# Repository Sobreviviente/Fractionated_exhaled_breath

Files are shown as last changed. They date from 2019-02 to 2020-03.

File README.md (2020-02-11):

# Fractionated_exhaled_breath
Locación de archivos para equipo médico desarrollado por PhD. Marcelo Tuesta, Fundación Doctor Jorge Kaplan Meyer.

Códigos elaborados por Carlos Pizarro, Centro de Innovación y Robótica.

Links de interés:

[Printed spirometer](http://iotmusings.com/low-cost-spirometer/)

[Printed spirometer 2](https://www.instructables.com/id/Low-Cost-Spirometer/)

[Printed spirometer 3](http://fabacademy.org/2019/labs/bahrain/students/zahra-almukhariq/projects/final-project/)

[Design and implementation of a spirometer](https://editorial.udistrital.edu.co/contenido/c-778.pdf)

[Lilly spirometer](http://langster1980.blogspot.com/2017/04/create-spirometer-using-msp7002dp.html)

[General spirometry info](http://docs.neu.edu.tr/library/6682401378.pdf)

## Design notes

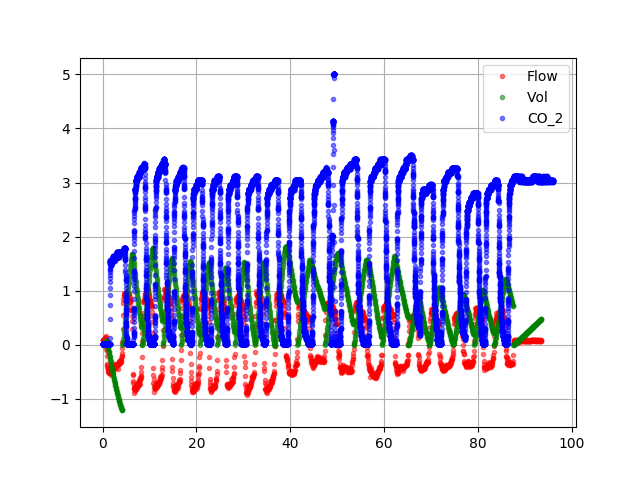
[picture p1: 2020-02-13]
Toma de datos co2 trigger 11-02-20/filtrados/c50-flow.png

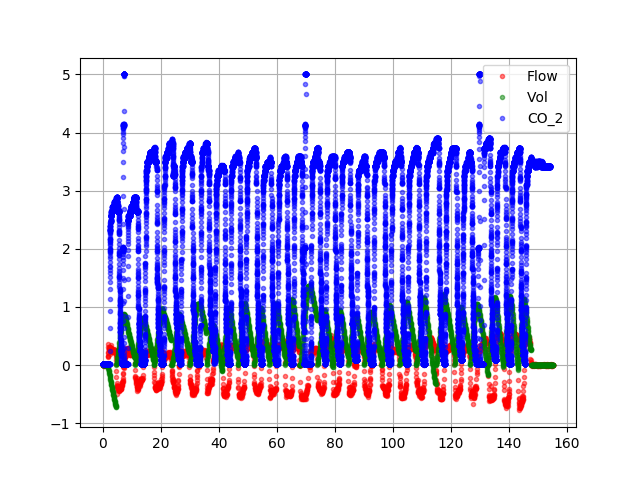
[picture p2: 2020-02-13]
Toma de datos co2 trigger 11-02-20/filtrados/c50-flow-2.png

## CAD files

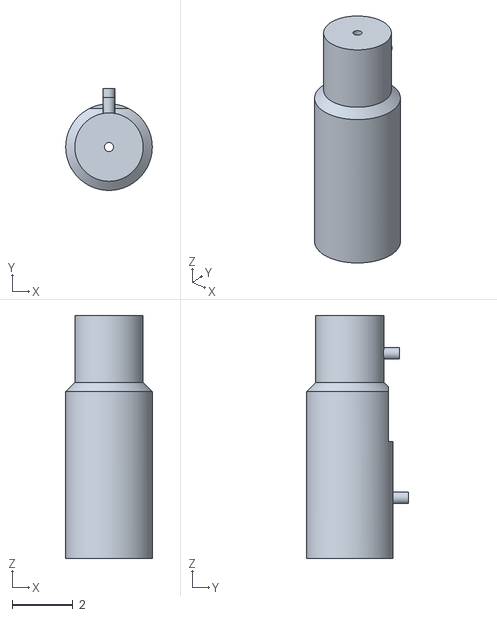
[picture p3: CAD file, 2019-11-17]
Int 3 2.stl
2.85 x 3.35 x 8.00

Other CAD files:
int 3.2.ipt

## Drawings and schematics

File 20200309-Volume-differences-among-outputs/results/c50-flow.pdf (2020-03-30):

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

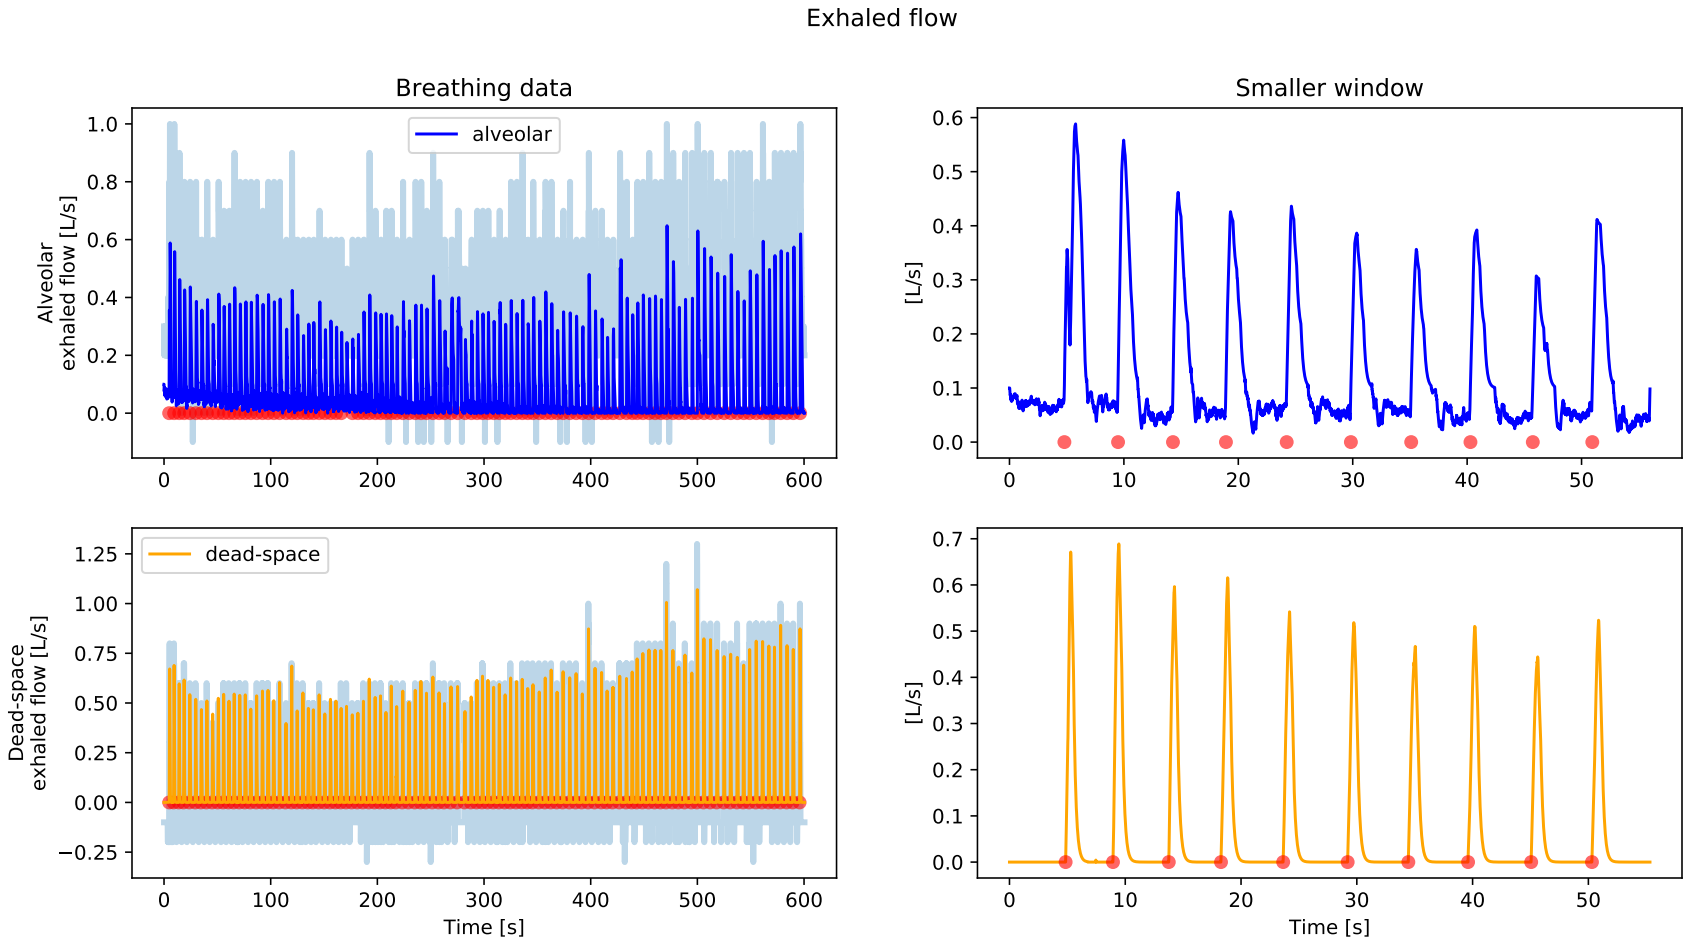
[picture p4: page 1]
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

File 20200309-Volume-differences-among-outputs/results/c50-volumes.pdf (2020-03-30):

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

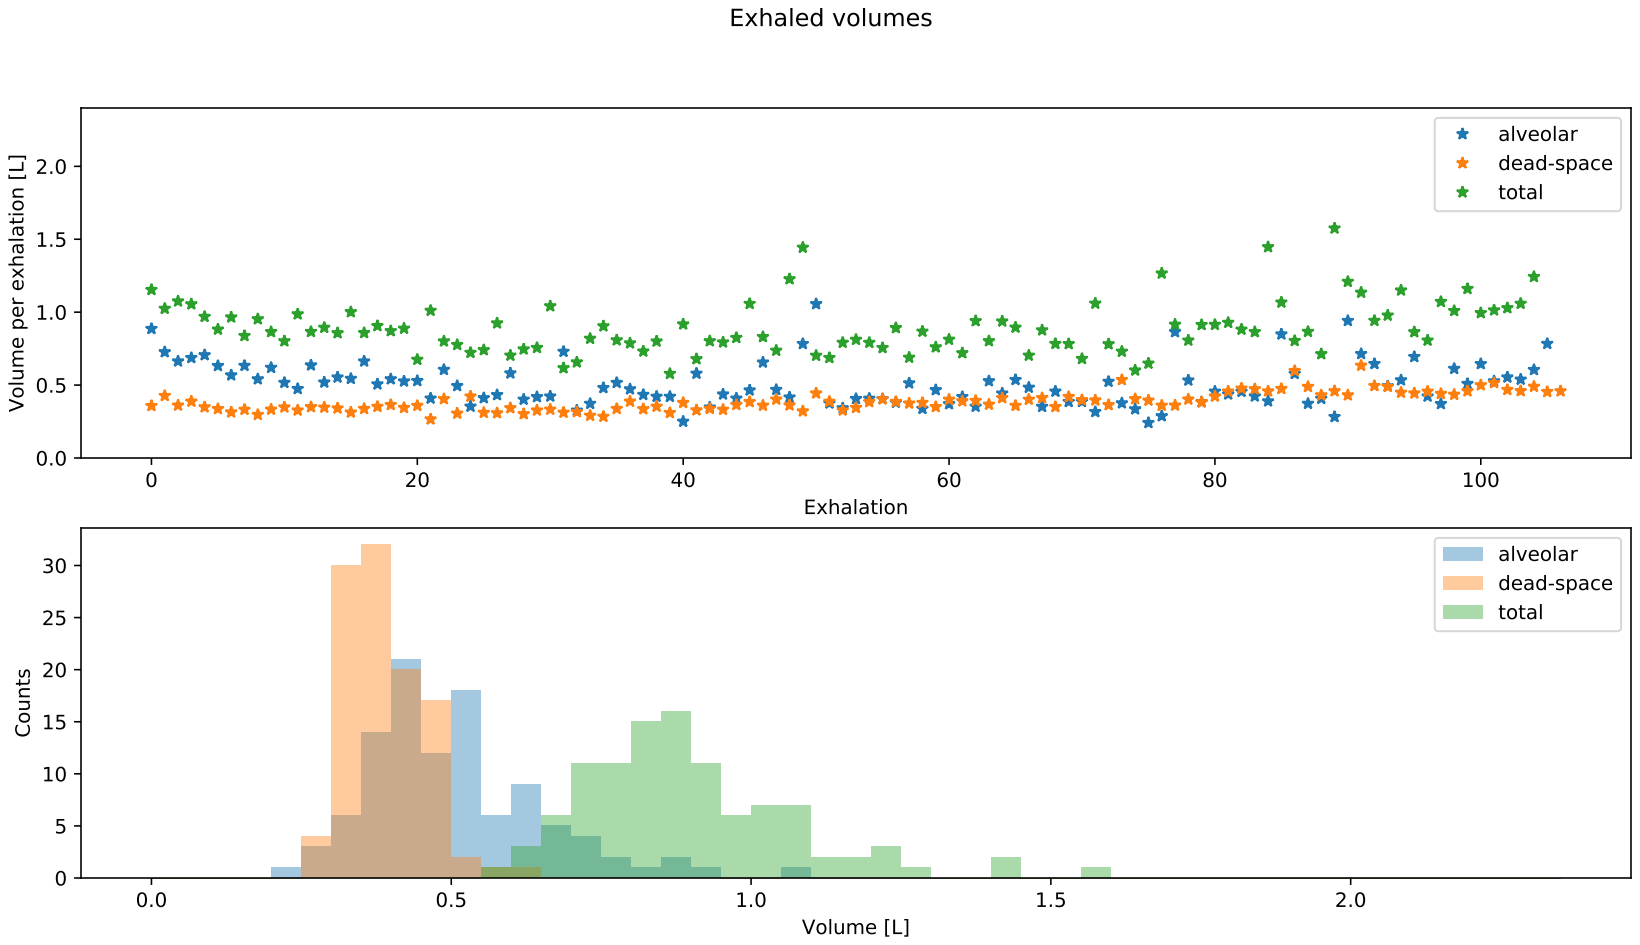
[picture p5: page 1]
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

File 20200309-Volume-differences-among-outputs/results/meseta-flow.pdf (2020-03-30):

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

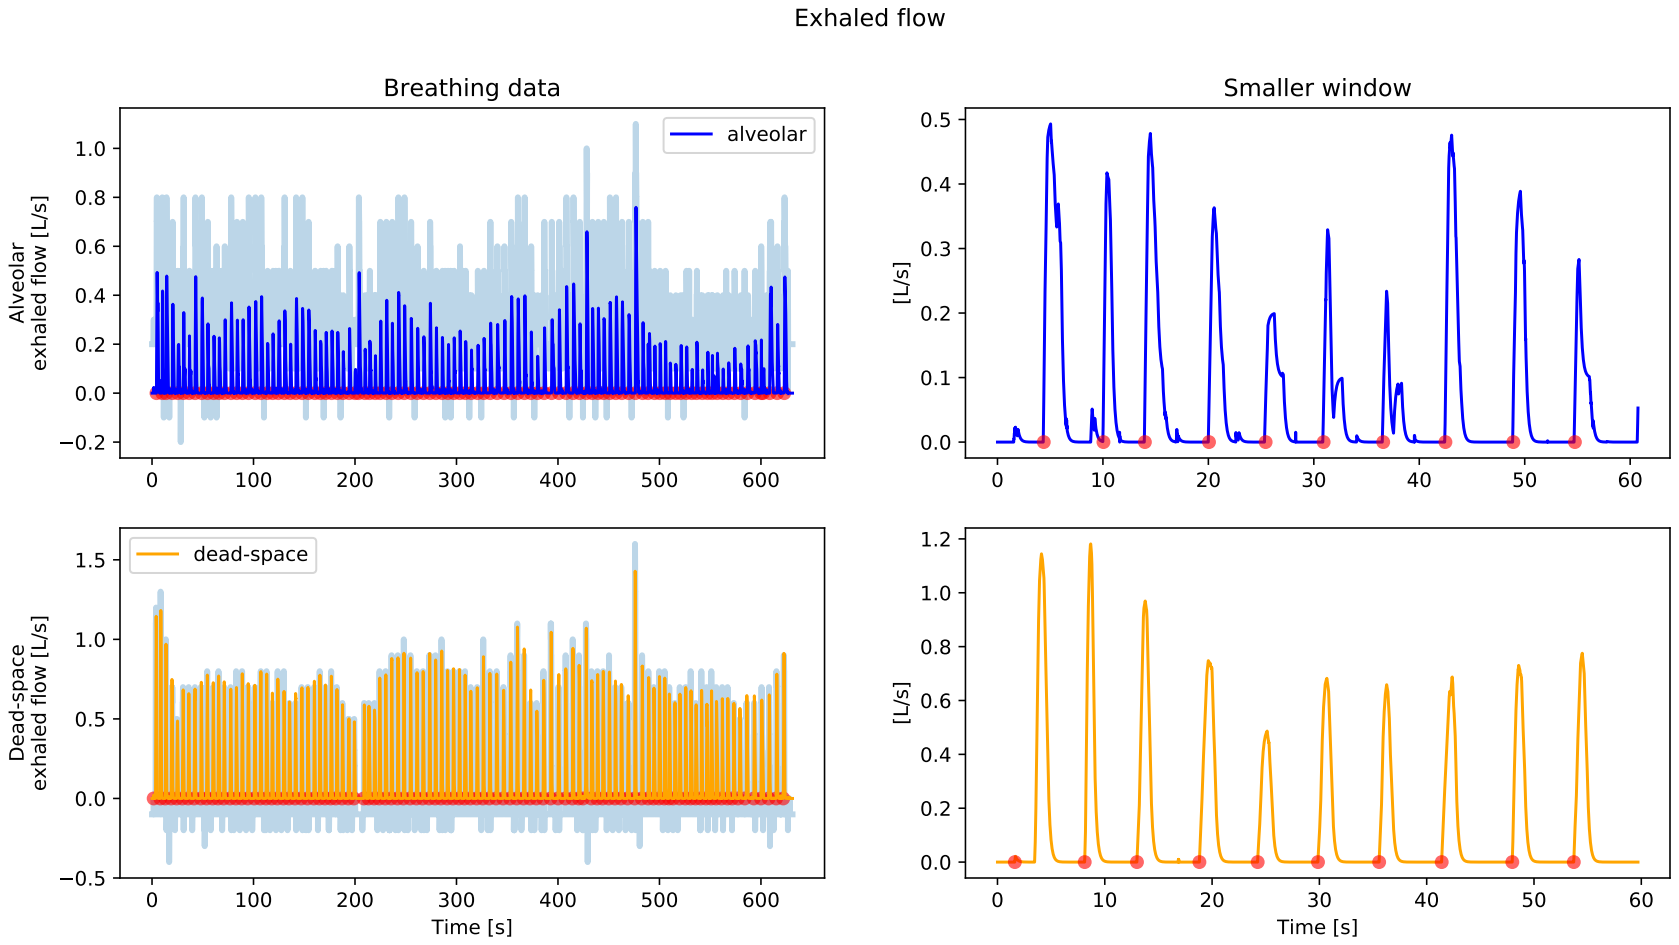
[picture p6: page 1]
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

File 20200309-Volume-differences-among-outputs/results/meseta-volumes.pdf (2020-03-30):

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

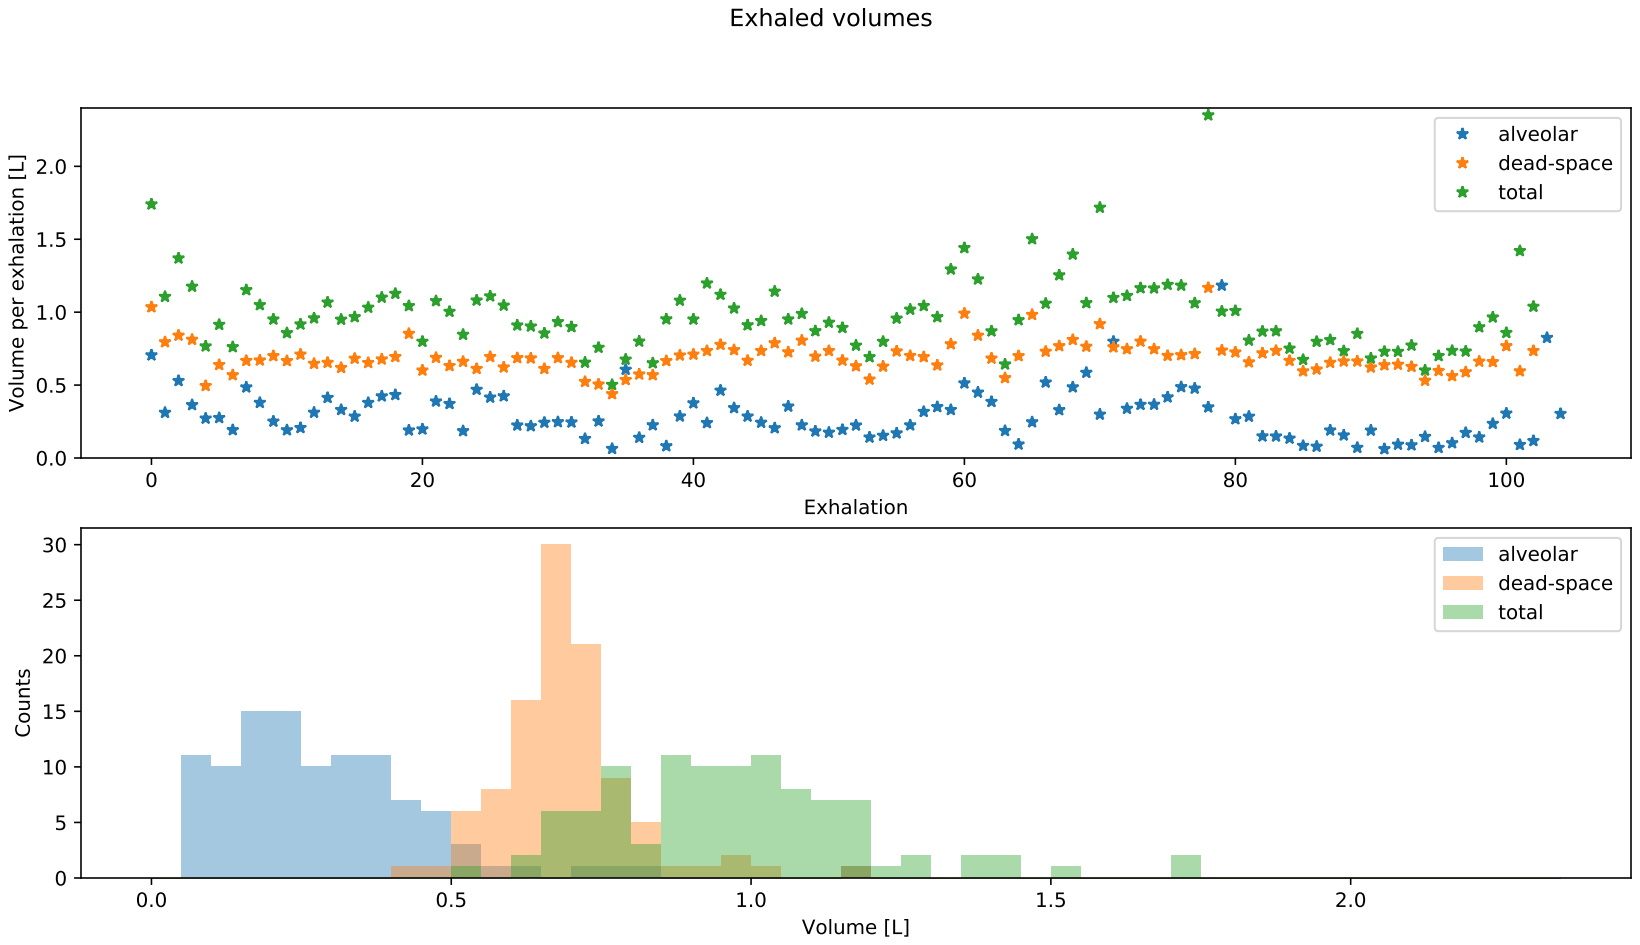
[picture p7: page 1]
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

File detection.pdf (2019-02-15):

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

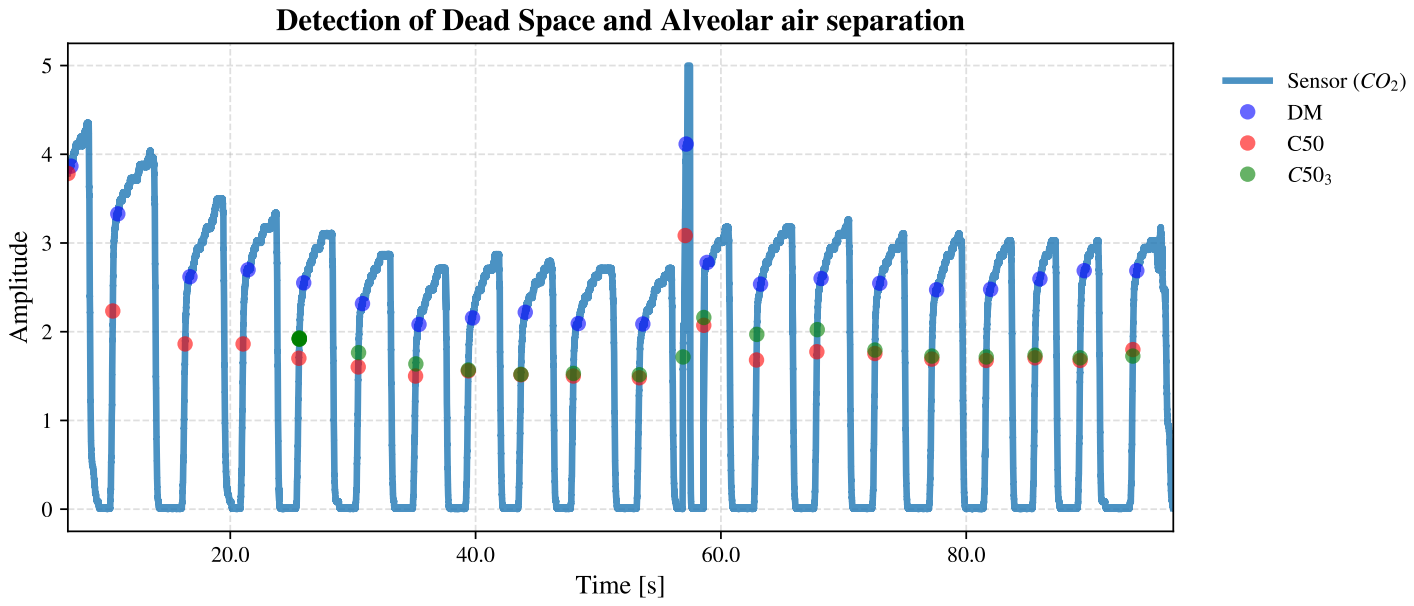
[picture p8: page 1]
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

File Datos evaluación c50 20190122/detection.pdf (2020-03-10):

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

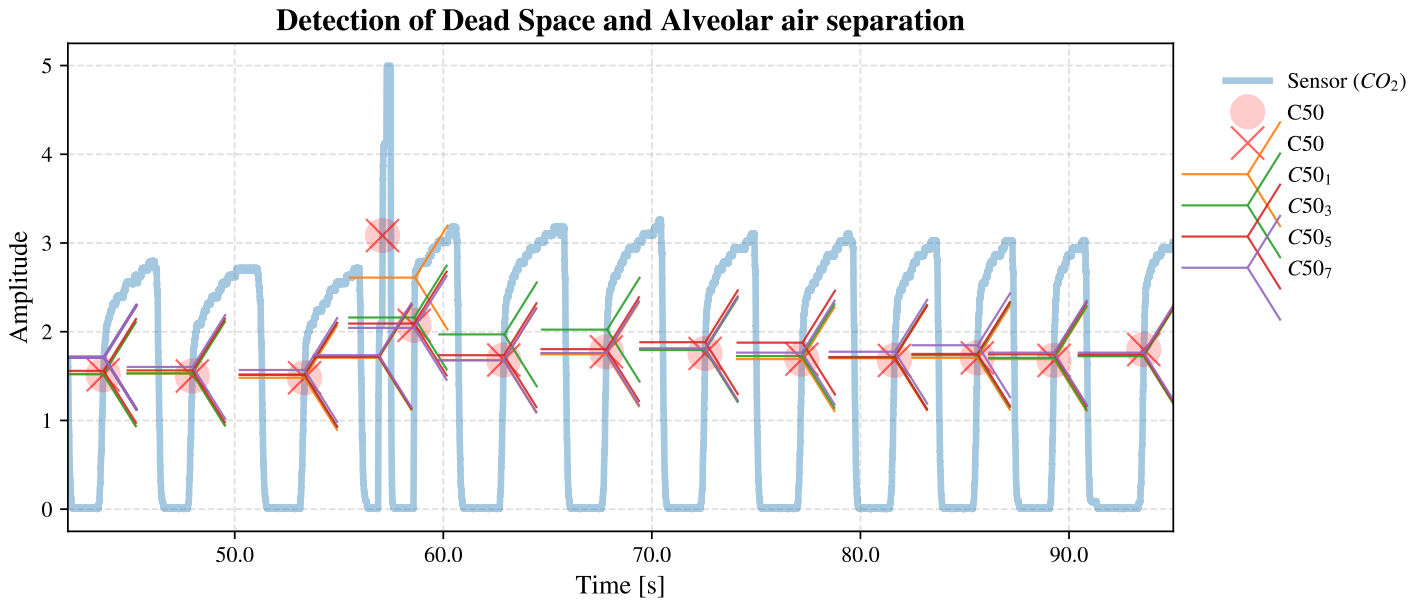
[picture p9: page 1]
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

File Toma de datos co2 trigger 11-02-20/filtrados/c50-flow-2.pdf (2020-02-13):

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

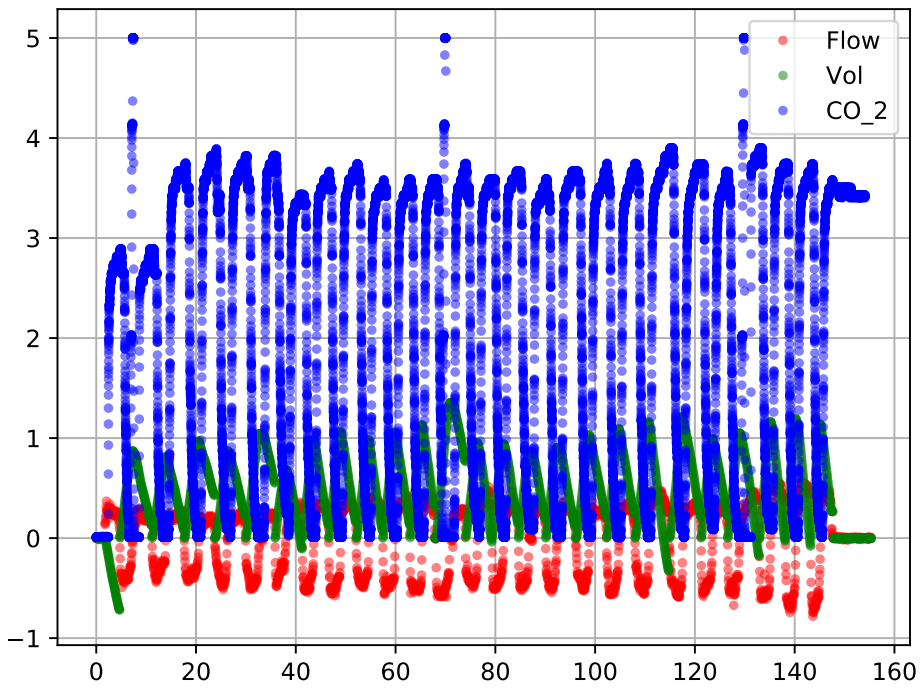
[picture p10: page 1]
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

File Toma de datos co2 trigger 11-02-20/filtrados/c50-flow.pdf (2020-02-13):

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

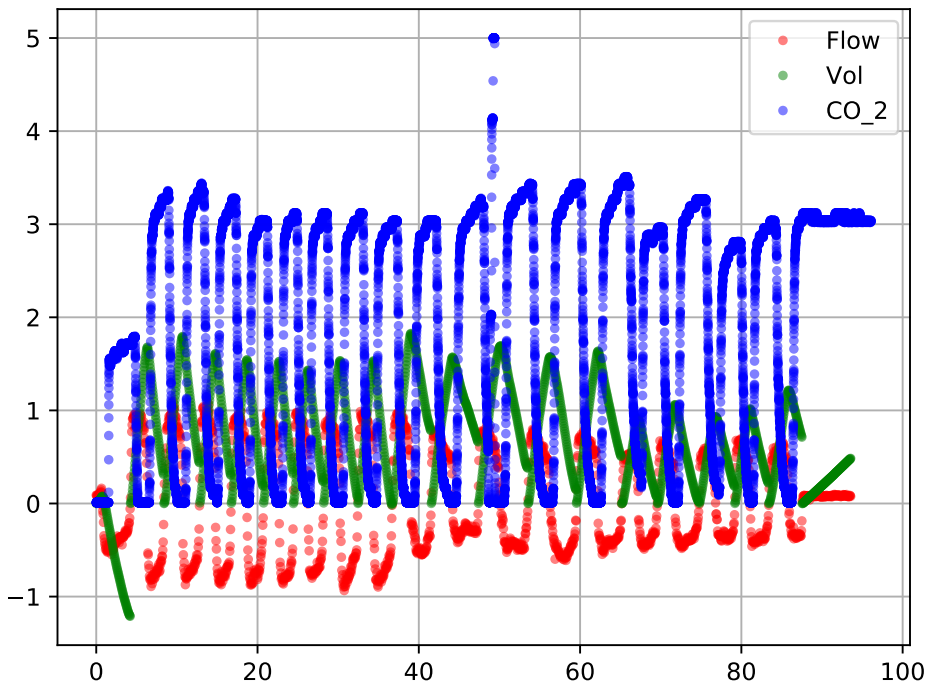
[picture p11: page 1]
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

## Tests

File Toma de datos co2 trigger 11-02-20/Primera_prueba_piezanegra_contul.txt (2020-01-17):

0.02098,2409288620,2409299,0.02986
0.02785,2409501544,2409512,0.09160
0.02785,2409781140,2409792,0.12042
0.03052,2411717296,2411727,0.87114
0.03052,2411763464,2411774,0.02116
0.07057,2411831860,2411842,0.04655
0.02976,2411855776,2411867,0.05767
0.06828,2411879712,2411890,0.07316
0.12665,2411903644,2411914,0.09517
0.06218,2411928724,2411939,0.11123
0.09613,2411966164,2411976,0.14080
0.03586,2412003604,2412014,0.15934
0.04730,2412041040,2412052,0.18064
0.02632,2412078484,2412089,0.19611
0.03319,2412115924,2412127,0.21395
0.04005,2412153364,2412164,0.23303
0.06294,2412190804,2412201,0.25696
0.05150,2412228244,2412238,0.27860
0.04730,2412265684,2412276,0.29989
0.07248,2412303136,2412314,0.32626
0.02022,2412362792,2412374,0.02199
0.02174,2412798112,2412809,0.16531
0.06371,2412822032,2412832,0.18027
0.21820,2412845984,2412857,0.21036
0.33188,2412869920,2412880,0.24451
0.42992,2412894960,2412906,0.28844
0.49210,2412932400,2412943,0.35533
0.54093,2412969844,2412981,0.42736
0.67216,2413007280,2413018,0.50553
0.75685,2413044724,2413056,0.59073
0.75189,2413082160,2413092,0.67118
0.74464,2413119600,2413130,0.75568
0.70459,2413157040,2413167,0.83572
0.73777,2413194480,2413205,0.91983
0.70039,2413231924,2413243,1.00179
0.73167,2413269360,2413280,1.08335
0.72976,2413306804,2413318,1.16701
0.81369,2413344240,2413355,1.25302
0.88617,2413381680,2413392,1.34278
0.95369,2413419120,2413429,1.43590
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

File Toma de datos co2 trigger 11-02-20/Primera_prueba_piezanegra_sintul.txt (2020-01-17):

2.61959,1028540448,1028551,5.20201
2.55245,1028577888,1028588,5.35435
2.47921,1028615328,1028626,5.50855
2.41131,1028652768,1028663,5.65661
2.51125,1028690208,1028701,5.81180
2.53033,1028727648,1028739,5.96758
2.41970,1028765088,1028775,6.11189
2.36591,1028802528,1028813,6.26252
2.38766,1028839968,1028850,6.40986
2.11604,1028877408,1028888,6.55232
2.01076,1028914848,1028925,6.68753
2.00809,1028952288,1028963,6.82630
1.86618,1028989736,1029001,6.96008
1.90356,1029027168,1029038,7.09164
1.74182,1029064608,1029075,7.21748
1.74716,1029102048,1029112,7.34352
1.63424,1029139488,1029150,7.46871
1.67277,1029176928,1029187,7.59203
1.82155,1029214368,1029225,7.72420
1.74258,1029251808,1029262,7.85007
1.66857,1029289248,1029300,7.97657
1.61784,1029326688,1029338,8.10113
1.57435,1029364128,1029374,8.21754
1.74983,1029401568,1029412,8.34708
1.61784,1029439008,1029449,8.46837
1.42634,1029476448,1029487,8.58532
1.25734,1029513888,1029524,8.69224
0.15984,1029551328,1029562,8.73140
0.02899,1029588776,1029600,8.74807
0.06447,1030248860,1030259,0.43121
0.04616,1030361708,1030372,0.06257
0.04616,1030519036,1030530,0.08748
0.04540,1030731924,1030743,0.11695
0.10567,1030778092,1030789,0.03854
0.13428,1030824232,1030835,0.04344
0.09422,1030881500,1030892,0.04509
0.14229,1030938756,1030949,0.05541
0.06104,1030973780,1030984,0.02228
0.05493,1031031048,1031042,0.03503
0.04349,1031054956,1031065,0.04739
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

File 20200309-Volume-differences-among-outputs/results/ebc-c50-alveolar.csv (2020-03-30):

start | end | volume
4.8 | 9.49 | 0.8862095103958444
9.49 | 14.29 | 0.7267876578773813
14.29 | 18.92 | 0.6635060401361577
18.92 | 24.23 | 0.6870290316965323
24.23 | 29.84 | 0.7061063877140579
29.84 | 35.11 | 0.6321993801062449
35.11 | 40.29 | 0.5679082054055556
40.29 | 45.74 | 0.63313496750012
45.74 | 50.94 | 0.5409160976201454
50.94 | 55.99 | 0.6195451129899768
55.99 | 60.98 | 0.5167137035342428
60.98 | 65.88 | 0.4745362277016411
65.88 | 71.09 | 0.6362130316414606
71.09 | 76.25 | 0.5188016796735437
76.25 | 81.44 | 0.5531982257852155
81.44 | 86.9 | 0.5440838656612225
86.9 | 92.37 | 0.6631409477341497
92.37 | 97.59 | 0.5060835650327001
97.59 | 102.99 | 0.5410553001332746
102.99 | 108.44 | 0.5261380702780186
108.44 | 114.5 | 0.5291754436900556
114.5 | 119.82 | 0.4088225360289564
119.82 | 124.96 | 0.6057315837603539
124.96 | 130.48 | 0.49481846637111704
130.48 | 135.43 | 0.3535004509640978
135.43 | 140.12 | 0.4114025079881202
140.12 | 145.53 | 0.43261954494099186
145.53 | 150.89 | 0.5814048738815037
150.89 | 156.15 | 0.40123948954407207
156.15 | 161.3 | 0.4188608197768126
161.3 | 166.16 | 0.42292958775837797
166.16 | 176.65 | 0.7295689840433791
176.65 | 181.89 | 0.3260135787325553
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

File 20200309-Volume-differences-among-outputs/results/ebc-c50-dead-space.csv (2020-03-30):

start | end | volume
4.85 | 8.94 | 0.358064465513996
8.94 | 13.76 | 0.4269477696528208
13.76 | 18.27 | 0.3609971732573878
18.27 | 23.64 | 0.3879990721000637
23.64 | 29.21 | 0.3489995485155068
29.21 | 34.45 | 0.33699956829402083
34.45 | 39.61 | 0.31399948998938815
39.61 | 45.06 | 0.33199951088236856
45.06 | 50.31 | 0.2969991233965058
50.31 | 55.33 | 0.3329991774964104
55.33 | 60.3 | 0.3479980144048592
60.3 | 65.22 | 0.32699896270985046
65.22 | 70.48 | 0.3501347913587115
70.48 | 75.67 | 0.3469950330662605
75.67 | 80.71 | 0.3409994811559704
80.71 | 86.34 | 0.31299940884935823
86.34 | 91.76 | 0.3379995928513026
91.76 | 96.97 | 0.35199947336349063
96.97 | 102.24 | 0.36499942904751925
102.24 | 107.87 | 0.34499934138563526
107.87 | 113.74 | 0.3589996111083369
113.74 | 119.25 | 0.2659993384007387
119.25 | 124.33 | 0.40499960860797224
124.33 | 129.62 | 0.30592100984609233
129.62 | 134.75 | 0.4228743895871633
134.75 | 139.44 | 0.31099930537437376
139.44 | 144.94 | 0.30799894458447546
144.94 | 150.16 | 0.3429996119278075
150.16 | 155.47 | 0.30199943346905106
155.47 | 160.64 | 0.3269995471874796
160.64 | 165.5 | 0.3329994028844408
165.5 | 170.57 | 0.3119993775837127
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

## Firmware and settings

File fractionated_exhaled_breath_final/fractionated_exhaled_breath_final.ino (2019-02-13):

#define PCe  0
#define Ce50 1
#define SUMA_TIEMPO 150000 // [ms]
float sensor_p=0;  // valor de sensor presion
float sensor_co2_1=0;  //valor de sensor co2 primer cable 
float sensor_co2_2=0;  //valor de sensor co2 segundo cable
char Key = '0';
int mensaje=0;
int estado_curva=0;
const int ledPin = 13; 
const int Bomba1 = 11;
const int Bomba2 = 12;
const int co2_1 = 23;
const int co2_2 = 22;
const int valv_blanca_1 = 16; //1 es el de la derecha
const int valv_negra_2 = 17;  // 2 es el de la izquierda 
const int valv_blanca_2 = 18;
const int valv_negra_1 = 19; 
unsigned long tiempo = 0;
unsigned long tiempo_t = 0;
uint8_t useMethod = PCe;
#define umbral_high 3.1
#define umbral_low 3.0
int estado_aux=0; 
float ultimos_3valores[3]={};
int c=0;
int pos=0;
float C50_maximo=-8;
float C50_minimo=8;
float C50_prom3=0;
bool C50_revisando = true;
unsigned long tiempo_trigger = 0; 

void setup() {
 Serial.begin(9600);
 pinMode( 20, INPUT); // pin 20 como input 
 pinMode( ledPin, OUTPUT);
 pinMode( Bomba1, OUTPUT);
 pinMode( Bomba2, OUTPUT);
 pinMode( co2_1, INPUT);
 pinMode( co2_2, INPUT);
 pinMode( valv_blanca_1, OUTPUT);
 pinMode( valv_negra_2, OUTPUT);
 pinMode( valv_blanca_2, OUTPUT);
 pinMode( valv_negra_1, OUTPUT);
  // put your setup code here, to run once:
  
  for (int i=0; i<3; i++){
      ultimos_3valores[i] = -1;
  }
}

void loop() {
  tiempo = millis();
  lectura_escaner();
  lectura_sensor();
  controla_bombas();

  if (useMethod == Ce50)
    C50();
  else if (useMethod == PCe)
    PC();
     
}

void C50_nuevoValor(float v) {
  c++;
  ultimos_3valores[c%3] = v;
}

void actualizar_promedio() {
  float prom = 0.0;
  for (int i=0; i<3; i++) {
    if (ultimos_3valores[i] == -1)
      break;
    prom += ultimos_3valores[i]/3;
  }
  
  C50_prom3 =  prom;
}

void C50() {
  if (sensor_co2_1 > 1 && !C50_revisando){
    
  
    C50_revisando = true;
    C50_maximo = -8;
    C50_minimo = 8;
  }
  else if (sensor_co2_1 <= 0.05 && C50_revisando){
          int promedio;
          promedio = (C50_maximo+C50_minimo)/2.0;
          ultimos_3valores[pos%3]=promedio;
          actualizar_promedio();
          pos+=1;   
          C50_revisando=false;
  }

  if (C50_revisando){
    if (sensor_co2_1>C50_maximo){
      C50_maximo=sensor_co2_1;
    }
    if (sensor_co2_1<C50_minimo){
      C50_minimo=sensor_co2_1;
  }  
  }
  
  if ((sensor_co2_1<C50_prom3) && estado_aux==0){
    estado_deadspace();
    estado_aux=1;
    
  }
  else if((sensor_co2_1>C50_prom3) && estado_aux==1){
    estado_biomarcador();
    estado_aux=0;
  }
}



void PC() {
  if (estado_curva==0 && sensor_co2_1 > 3.0){    // CURVA SUBIENDO
    estado_curva=1;
  }
  else if (estado_curva==1 && sensor_co2_1 < 0.5){  // 
    estado_curva=2;
    tiempo_trigger = tiempo + SUMA_TIEMPO; 
  }
  else if (estado_curva=2 && tiempo>tiempo_trigger){            // TRIGGER 
    estado_curva=3;
  }
  else if(estado_curva=3 && sensor_co2_1<0.05){
    estado_curva=0;
  }
}

void estado_deadspace(){
  digitalWrite(valv_negra_1,HIGH);
  digitalWrite(valv_negra_2,LOW);
  digitalWrite(valv_blanca_1,HIGH);
  digitalWrite(valv_blanca_2,LOW);
}

void estado_biomarcador(){
  digitalWrite(valv_negra_1,LOW);
  digitalWrite(valv_negra_2,HIGH);
  digitalWrite(valv_blanca_1,LOW);
  digitalWrite(valv_blanca_2,HIGH);
}

void lectura_sensor(){
  float cValue = (5.0*analogRead(20))/1023.0;
  sensor_p = 0.95*sensor_p + 0.05*cValue;
  //Serial.println(sensor_p,4);
}

void controla_bombas(){ 
    lectura_sensor();
    if (sensor_p >= umbral_high){
      digitalWrite(Bomba1, LOW);
      digitalWrite(Bomba2, LOW);
    }
    else{
      if(sensor_p<umbral_low) {
        digitalWrite(Bomba1,HIGH);
        digitalWrite(Bomba2,HIGH);
      
    }
}
}
void lectura_escaner(){
  sensor_co2_1 = (5.0*analogRead(23))/1023.0;
  sensor_co2_2 = (5.0*analogRead(22))/1023.0;
  //Serial.print (analogRead(23));
  //Serial.print(",");
  //Serial.print (analogRead(22));
  //Serial.print(",");
  //Serial.print(sensor_co2_1,4);
  //Serial.print(",");
  //Serial.println(sensor_co2_2,4);
}


void prueba_globos_alternando(){
   if(tiempo - tiempo_t> 7000){
    digitalWrite(valv_negra_1,LOW);
    //digitalWrite(valv_blanca_1,HIGH);
    digitalWrite(valv_negra_2,LOW);
    //digitalWrite(valv_blanca_2,LOW);
    tiempo_t = tiempo;
  }
 else if (tiempo - tiempo_t > 5000){
   // digitalWrite(valv_negra_1,LOW);
    //digitalWrite(valv_blanca_1,HIGH);
   // digitalWrite(valv_negra_2,HIGH);
    //digitalWrite(valv_blanca_2,HIGH);
  }
  else if (tiempo - tiempo_t > 3000){
    //digitalWrite(valv_negra_1, LOW);
    //digitalWrite(valv_blanca_1,LOW);
    //digitalWrite(valv_negra_2,HIGH);
    //digitalWrite(valv_blanca_2,HIGH);
  }
  else if (tiempo - tiempo_t > 1000){
    digitalWrite(valv_negra_1, HIGH);
    //digitalWrite(valv_blanca_1,HIGH);
    digitalWrite(valv_negra_2,LOW);
    //digitalWrite(valv_blanca_2,HIGH);
  }
}

//CODIGO PRUEBAS POR SERIAL 

 /*
 if(Serial.available()>0){
    Key=Serial.read();
    Serial.print (Key);
     
    }
    
    
  
  if (Key=='1'){
  
    digitalWrite(valv_negra_1,LOW);
    digitalWrite(valv_negra_2,HIGH);
    digitalWrite(valv_blanca_1,LOW);
    digitalWrite(valv_blanca_2,HIGH);
  }
  else if (Key=='0'){
    digitalWrite(valv_negra_1,HIGH);
    digitalWrite(valv_negra_2,LOW);
    digitalWrite(valv_blanca_1,HIGH);
    digitalWrite(valv_blanca_2,LOW);
  }
  else if (Key == '2'){
    digitalWrite(valv_blanca_2,HIGH);
  }

  */
  // put your main code here, to run repeatedly:

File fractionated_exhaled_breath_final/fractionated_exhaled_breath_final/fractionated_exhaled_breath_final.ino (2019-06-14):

#include "pc.h"
#include "estados_salida.h"
#include "defines.h"
#include "funciones_ADS.h"
#include "pruebas.h"
#include "C50.h"

unsigned long tiempo = 0;
uint8_t useMethod = PCe;

void setup() {
 Serial.begin(9600);
 pinMode( Presion, INPUT);
 pinMode( ledPin, OUTPUT);
 pinMode( Bomba1, OUTPUT);
 pinMode( Bomba2, OUTPUT);
 pinMode( co2_1, INPUT);
 pinMode( co2_2, INPUT);
 pinMode( valv_blanca_1, OUTPUT);
 pinMode( valv_negra_2, OUTPUT);
 pinMode( valv_blanca_2, OUTPUT);
 pinMode( valv_negra_1, OUTPUT);
 pinMode( pin_switch, INPUT);
 
 init();
}

void loop() {
  tiempo = micros();
  float escaner_value=lectura_escaner();
  lectura_sensor();
  controla_bombas();
  
  useMethod = digitalRead(pin_switch);

  if ( sensor_co2_1 > 4.95 ) // Sensor saturado
    init();
  
  if (useMethod == Ce50) {
     Serial.println("C50");
     C50();
  }
  else if (useMethod == PCe) {
     Serial.print("DM: ");
     PC(escaner_value,tiempo );
  }
}

void init() {
 estado_deadspace();

 if (useMethod == Ce50) 
   C50_init();
 else if (useMethod == PCe)
   PC_init();
  
}

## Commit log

2019-02-13 Update fractionated_exhaled_breath_final.ino
    Agregadas funciones deadspace y biomarcador para funcionamiento de globos
2019-02-13 Update fractionated_exhaled_breath_final.ino
    Condicion de Revisando para actualizar maximo y minimo
2019-02-13 Activación de globos
    acción de funcinoes para 2 estados de globos añadidas
2019-02-13 Code update
    Para no corregir todo punto a punto copié la corrección
2019-12-12 Add files via upload
    Código para probar pieza de espirometro
2019-12-12 Añadida unidad de volumen
2020-01-14 Add files via upload
    Código para el espirometro con el dt corregido, probado en pieza verde
2020-01-17 Add files via upload
    Datos primera prueba, los datos están ordenados como: presión,tiempo micros, tiempo millis, volumen
2020-01-17 Add files via upload
    Datos de pieza sin tul, el formato es presion,tiempomicro,tiempomilli,volumen
2020-02-11 Add files via upload
    Toma de datos 11-02-20 en UNAB con capnografo y espirometro powerlab
2020-02-12 Data filtered
2020-02-13 Data for volume comparison
    [EBC-CN.ods, EBC-CP-1.ods, EBC-CP-2.ods]
2020-02-13 Data 20200213 in liter
    [EBC-CN.ods, EBC-CP-1.ods, EBC-CP-2.ods]
2020-03-03 Added different c50 filter's time constant
2020-03-30 Fixed breathing calculations
    [ebc-c50-alveolar.csv, ebc-c50-dead-space.csv, ebc-c50-total.csv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]
